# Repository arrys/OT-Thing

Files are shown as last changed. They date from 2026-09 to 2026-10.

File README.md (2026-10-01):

# OTthing

**A compact WiFi <-> OpenTherm (master & slave) interface**

## Project homepage

https://www.seegel-systeme.de/2025/01/05/ot-thing-das-universelle-wifi-opentherm-interface/

OTthing OTthing board
*OTthing board*

OTthing web UI OTthing web UI status
*OTthing web interface*

OTthing Home Assistant Dashboard OTthing Home Assistant dashboard
*Home Assistant integration*

## Overview

OTthing is a versatile OpenTherm gateway that connects your heating system to the Internet via WiFi. It acts as an OpenTherm master (controlling your boiler) and/or slave (integrating with room thermostats), providing real-time monitoring and control through a modern web interface and Home Assistant integration.

### Key Features

* **Dual OpenTherm Modes**: Operate as both an OpenTherm master and a slave simultaneously
* **Single-Board Compact Design**: Cost-efficient SMD-based single-board hardware with a small enclosure footprint
* **OpenTherm Compatibility**: Works with OpenTherm-compatible equipment that implements the functions supported by OTthing; available features vary by device
* **USB-C Powered**: Simple and reliable power supply through a standard USB-C connector
* **Web Dashboard**: Real-time status monitoring with system metrics
* **Home Assistant Integration**: Native MQTT discovery and seamless HA integration
* **Multi-Zone Support**: Control up to 2 heating circuits with independent parameters
* **Time Program**: Built-in scheduling for automatic heating setpoint changes
* **Heating Curve Control**: Outdoor-compensated flow temperature control with configurable curve parameters
* **Flow & Setpoint Management**: Fine-grained control for CH temperature targets, modes, and operating limits
* **Raw OpenTherm Tools**: Direct read/write request endpoint for diagnostics and advanced integrations
* **Real-Time Telemetry**: Live updates via WebSocket for logs and status changes
* **REST API**: Full HTTP interface for status, configuration, control commands, and topic discovery
* **WiFi Provisioning**: Built-in network scan and credential setup through the web interface
* **OTA Firmware Update**: In-browser firmware upload endpoint with automatic reboot on success
* **Local Data Export**: Device data and diagnostics export from the web UI for troubleshooting
* **External Inputs & Sensors**: Optional DS18B20, pulse input, or photointerrupter support (for example, condensate monitoring)
* **Selectable Operating Strategies**: Run OTthing as a full heating controller or in monitoring-first mode for telemetry-only operation
* **Automatic Bypass Behavior**: Allows you to restore conventional room-thermostat operation without rewiring
* **Failsafe Runtime Status**: Device health and communication state tracking for robust operation
* **Local Control**: Responsive web UI with no cloud dependency
* **Modular Design**: Extensible architecture supporting multiple integrations
* **Open-Source Platform**: Open hardware and firmware for custom extensions and modifications
* **Advanced Configuration**: Room modes (off/heat/auto), flow control, heating curves, and more
* **Detailed Logging**: Real-time log streaming to monitor system behavior
* **Turbo Mode**: Temporarily raises the flow target by a configurable amount and duration
* **Automatic Suspend**: Optional suspension based on outside temperature, room conditions, and minimum flow thresholds
* **Customizable dashboard**: add metrics to dashboard

## Architecture

The firmware consists of several functional modules:

* **OpenTherm Control** (`otcontrol.cpp`): Manages master/slave communication with the boiler
* **Master Requests** (`masterrequests.cpp`): Builds and schedules OpenTherm master requests and polling cycles
* **OpenTherm Values** (`otvalues.cpp`): Stores, normalizes, and exposes decoded OpenTherm data points
* **Heating Curve** (`heatingcurve.cpp`): Calculates the target flow temperature from heating-curve parameters
* **MQTT Integration** (`mqtt.cpp`): Publishes device state and subscribes to control topics
* **Device Status** (`devstatus.cpp`): Tracks runtime health, connectivity, and status flags
* **Auxiliary Input** (`auxInput.cpp`): Handles external input signals for additional control logic
* **Web Portal** (`portal.cpp`): Serves the responsive dashboard and API endpoints
* **Heating Control** (`CHcontrol.cpp`): Manages heating circuits, setpoints, and modes
* **Sensor Integration** (`sensors.cpp`): Collects data from external sensors
* **Configuration Management** (`devconfig.cpp`): Handles persistent device settings

## Hardware

* **MCU**: ESP32-C3 (or a compatible MCU with UART pins)
* **Communication**: OpenTherm interface
* **Power**: via USB
* **Optional**: DS18B20 1-Wire temperature sensors and auxiliary inputs

OpenTherm support and available controls depend on the boiler or other equipment. Check the device documentation and OTthing schematics before installation. Disconnect equipment from mains power before wiring; have boiler wiring performed by a qualified installer where required. Connect OpenTherm through the board's designated terminals, never directly to MCU GPIO pins.

## Installation & Setup

1. **Hardware Setup**:

   - Connect the OpenTherm slave side (boiler / ventilation / solar storage) to the **Boiler** screw terminal on OTthing
   - Optionally connect the room unit to the **Roomunit** screw terminals on OTthing
   - Connect OTthing to a USB-C power supply

2. **Access the Web Interface**:

   - The device creates a WiFi access point for provisioning or connects to its configured network
   - The default access point password is `12345678`; change it before deployment
   - Access the web UI at `http://<otthing-ip>/` (default: 4.3.2.1)

3. **Configure**:

   - Set your boiler type and heating circuit parameters
   - Configure the MQTT broker if you are using Home Assistant
   - Adjust setpoints, heating curves, and control modes

### Build and Flash (Developers)

Install PlatformIO, then run these commands from the `Firmware/` directory:

```bash
platformio run --environment release
platformio run --environment release --target upload
platformio run --environment release --target uploadfs
```

The first command builds the firmware. The next two upload the firmware and the LittleFS web assets; perform both uploads when installing a complete build. The firmware project reads access point SSID, password, and hostname from `default.ini` unless overridden by the build environment. Set a unique access point password before deploying devices.

## API Reference

OTthing exposes the following REST endpoints and WebSocket connection:

When web authentication is configured, protected endpoints require a valid login session. Requests without a valid session return 401; log in through the web UI before using these endpoints.

### Core Status Endpoints

* **`GET /`** - Web dashboard (HTML)
* **`GET /status`** - Current device and boiler status (JSON)
* **`GET /config`** - Device configuration and settings (JSON)
* **`POST /config`** - Update device configuration (JSON body)
* **`GET /otitems`** - Raw OpenTherm items and values from master and slave (JSON)
* **`GET /topics`** - List all available MQTT control topics (text/plain)

### Control Endpoints

* **`GET /set?key=value`** - Update settings via query parameters
- Examples: `/set?chSetTemp1=50`, `/set?chMode1=heat`, `/set?maxModulation=100`
  - Use `/topics` to discover supported control keys. URL-encode values when they contain reserved characters.
  - Returns 200 on success, 503 if the value cannot be set

* **`GET /slaverequest?id=X&rw=Y&data=HEX`** - Send a raw OpenTherm slave request
  - `id`: OpenTherm message ID (integer)
  - `rw`: 1 for READ_DATA, 0 for WRITE_DATA
  - `data`: Hex-encoded data value
- Returns JSON with response type, ID, and data
  - Returns 503 if a parameter is missing or the OT transaction does not complete

* **`GET /testdata`** / **`POST /testdata`** - Loopback test data for the local OT slave
  - GET returns the current table as JSON (used by `tools/settestdata.py`)
  - POST accepts a JSON object of `{"<name>": <0..65535>}` and updates the table
  - Only meaningful in loopback test mode (`otMode: 4`)

### System Endpoints

* **`GET /scan`** - Scan for available WiFi networks
  - Returns JSON with the SSID, RSSI, and channel for each network
  - Status field: -2 (scanning in progress), -1 (failed), 0+ (number of networks found)

* **`POST /setwifi`** - Configure WiFi credentials
- Parameters: `ssid` and `pass` (URL-encoded), both required
  - Starts a WiFi connection attempt; does not reboot. The device comes back
    on the new network within a few seconds

* **`GET /reboot`** - Trigger a device reboot
  - Returns 200 and schedules a reboot

* **`POST /update`** - Firmware update (binary upload)
  - Returns 200 on success, 500/503 on error
  - Triggers an automatic reboot if the update succeeds

### Real-time Communication

* **`WebSocket /ws`** - Real-time updates and log streaming
  - Receives log messages and status updates
  - Can be used to monitor device behavior in real time

### Authentication

All endpoints are open on the local network by default. Set a Web UI password in
the web interface (or via `POST /auth/setup`) to require a login. Once a password
is configured, the endpoints above require a session cookie.

* **`GET /auth/state`** - Reports whether a password is configured and whether the current session is valid
* **`POST /auth/login`** - `password` field; returns a session cookie
* **`POST /auth/logout`** - Ends the current session
* **`POST /auth/setup`** - `password` (and `delete=1`) to set or remove the password

Note that `/ws` is not covered by the session check.

## Testing & Development

A Python mock server is included for local UI and API testing. Install its dependencies and start it from the `Firmware/` directory:

```bash
python -m pip install -r requirements.txt
python tools/mock_otthing.py
```

The server listens on `http://127.0.0.1:8081/`. It is useful for UI development and API integration, but it does not replace testing against physical OpenTherm hardware.

### MQTT Notes

The device subscribes to control topics under `otthing/<device-id>/<key>/set`; `/topics` lists the supported keys. Home Assistant discovery is provided through MQTT when a broker is configured.

Changes sent through the web API are also published to the corresponding MQTT `/set` topic as retained messages. A broker can replay retained commands when the device reconnects, including after a reboot. Keep this in mind for temporary controls such as Turbo mode, and clear any stale retained command from the broker when needed.

### Troubleshooting

* **Cannot reach the web UI**: Confirm the phone or computer is connected to the OTthing access point or the same network as the device, then check the device IP.
* **No OpenTherm communication**: Check the board terminals, wiring polarity where applicable, boiler compatibility, and the device's status and logs.
* **Home Assistant entities are missing**: Confirm broker connectivity and MQTT discovery settings, then review device logs and the broker's topics.
* **A setting returns 401**: Log in through the web UI and retry the request with the browser session.
* **A temporary action returns after reboot**: Check whether a retained MQTT `/set` command is replaying it.

## Schematics

OTthing schematic 1 OTthing schematic page 1
OTthing schematic 2 OTthing schematic page 2

## Discussion

https://community.home-assistant.io/t/ot-thing-an-opentherm-wifi-gateway-with-integrated-ot-master-slave/824667

## Reporting issues

When reporting issues, please supply:

* Brand and model of the boiler and room unit
* OTthing firmware version and the steps that reproduce the issue
* Log
* Status JSON
* Configuration JSON
* OT items JSON
* Data history JSON

All of this data can be exported from OTthing using the export function at the bottom of the web UI.

## Contributing

* Make changes in a new branch based on the [`develop`](../../tree/develop) branch.
* Address only one issue per PR.
* Create the PR against the [`develop`](../../tree/develop) branch.

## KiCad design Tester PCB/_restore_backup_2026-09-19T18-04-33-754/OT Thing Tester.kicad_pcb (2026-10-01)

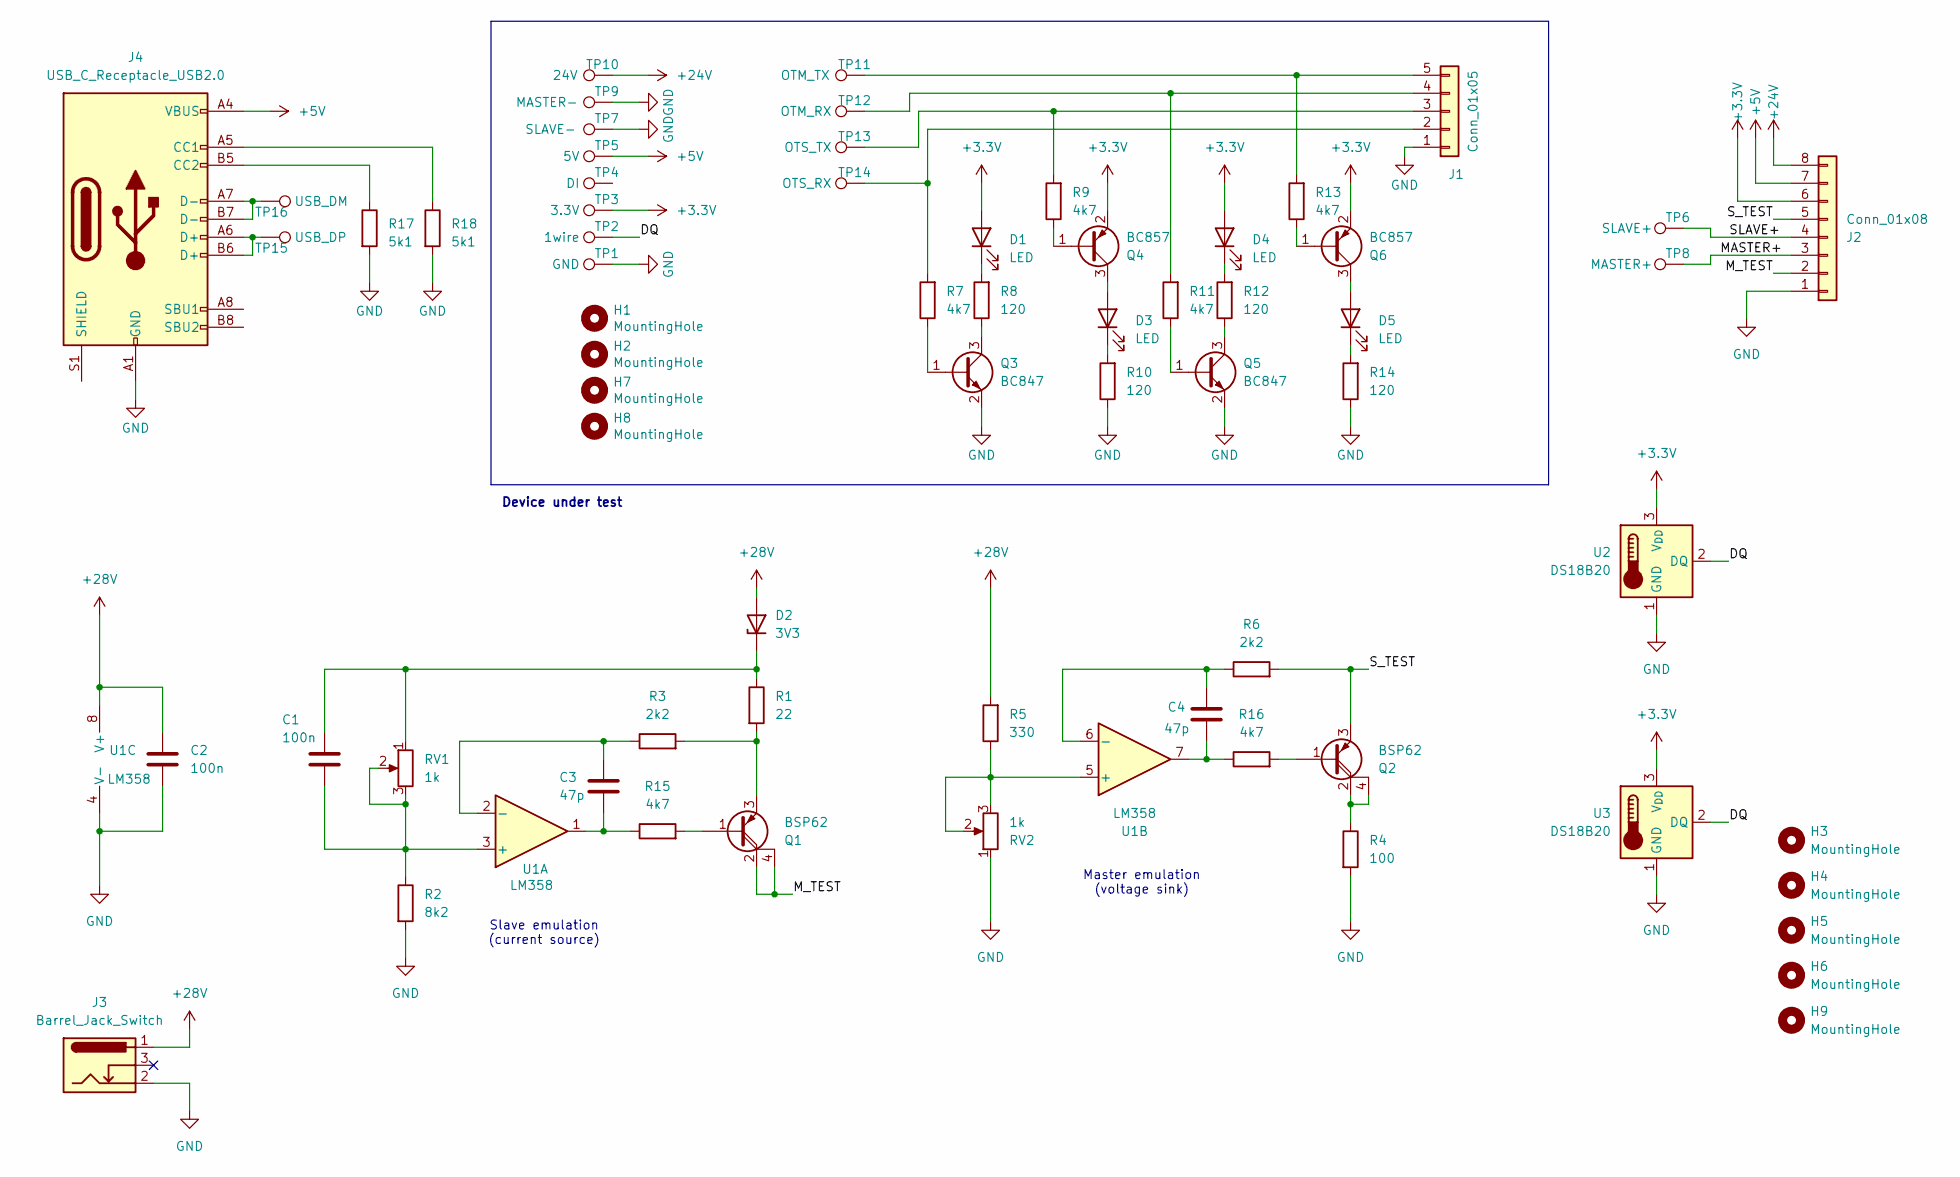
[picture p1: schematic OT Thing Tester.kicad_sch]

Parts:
C1, C2: 100n; C_0805_2012Metric
C3, C4: 47p; C_0805_2012Metric
D1, D3, D4, D5: LED; LED_0805_2012Metric
D2: 3V3; D_MiniMELF
H1, H2, H7, H8: MountingHole; MountingHole_2.7mm_M2.5
H3, H4, H5, H6, H9: MountingHole; MountingHole_3.2mm_M3_DIN965_Pad
J1: Conn_01x05; PinHeader_1x05_P2.54mm_Vertical
J2: Conn_01x08; PinHeader_1x08_P2.54mm_Vertical
J3: Barrel_Jack_Switch; BarrelJack_GCT_DCJ200-10-A_Horizontal
J4: USB_C_Receptacle_USB2.0; USB_C_Receptacle_HRO_TYPE-C-31-M-12; LCSC C2927038
Q1, Q2: BSP62; SOT-223
Q3, Q5: BC847; SOT-23
Q4, Q6: BC857; SOT-23
R1: 22; R_0805_2012Metric
R2: 8k2; R_0805_2012Metric
R3, R6: 2k2; R_0805_2012Metric
R4: 100; R_0805_2012Metric
R5: 330; R_0805_2012Metric
R7, R9, R11, R13, R15, R16: 4k7; R_0805_2012Metric
R8, R10, R12, R14: 120; R_0805_2012Metric
R17, R18: 5k1; R_0805_2012Metric; LCSC C118848
RV1, RV2: 1k; Potentiometer_Bourns_3266Y_Vertical
TP1: GND; TestPoint_THTPad_D2.0mm_Drill1.1mm
TP2: 1wire; TestPoint_THTPad_D2.0mm_Drill1.1mm
TP3: 3.3V; TestPoint_THTPad_D2.0mm_Drill1.1mm
TP4: DI; TestPoint_THTPad_D2.0mm_Drill1.1mm
TP5: 5V; TestPoint_THTPad_D2.0mm_Drill1.1mm
TP6: SLAVE+; TestPoint_THTPad_D2.0mm_Drill1.1mm
TP7: SLAVE-; TestPoint_THTPad_D2.0mm_Drill1.1mm
TP8: MASTER+; TestPoint_THTPad_D2.0mm_Drill1.1mm
TP9: MASTER-; TestPoint_THTPad_D2.0mm_Drill1.1mm
TP10: 24V; TestPoint_THTPad_D2.0mm_Drill1.1mm
TP11: OTM_TX; TestPoint_THTPad_D2.0mm_Drill1.1mm
TP12: OTM_RX; TestPoint_THTPad_D2.0mm_Drill1.1mm
TP13: OTS_TX; TestPoint_THTPad_D2.0mm_Drill1.1mm
TP14: OTS_RX; TestPoint_THTPad_D2.0mm_Drill1.1mm
TP15: USB_DP; TestPoint_THTPad_D2.0mm_Drill1.1mm
TP16: USB_DM; TestPoint_THTPad_D2.0mm_Drill1.1mm
U1: LM358; SO-8_3.9x4.9mm_P1.27mm
U2, U3: DS18B20; TO-92_Inline

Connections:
+3.3V: D1.2 (A), D4.2 (A), J2.6, Q4.2 (E), Q6.2 (E), TP3.1 (1_1), U2.3 (V_{DD}), U3.3 (V_{DD})
+5V: J2.7, J4.A4 (VBUS), J4.A9 (VBUS), J4.B4 (VBUS), J4.B9 (VBUS), TP5.1 (1_1)
+24V: J2.8, TP10.1 (1_1)
+28V: C2.1, D2.2 (A), J3.1, R5.2, U1.8 (V+)
/DQ: TP2.1 (1_1), U2.2 (DQ), U3.2 (DQ)
/MASTER+: J2.3, TP8.1 (1_1)
/M_TEST: J2.2, Q1.2 (C), Q1.4 (C)
/SLAVE+: J2.4, TP6.1 (1_1)
/S_TEST: J2.5, Q2.3 (E), R6.2
GND: C2.2, J1.1, J2.1, J3.2, J4.A1 (GND), J4.A12 (GND), J4.B1 (GND), J4.B12 (GND), Q3.2 (E), Q5.2 (E), R2.2, R4.2, R10.1, R14.1, R17.2, R18.2, RV2.1, TP1.1 (1_1), TP7.1 (1_1), TP9.1 (1_1), U1.4 (V-), U2.1 (GND), U3.1 (GND)
unnamed: C3.2, R15.1, U1.1
unnamed: C4.2, R16.1, U1.7
unnamed: D1.1 (K), R8.2
unnamed: C1.2, D2.1 (K), R1.1, RV1.1
unnamed: D3.2 (A), Q4.3 (C)
unnamed: D3.1 (K), R10.2
unnamed: D4.1 (K), R12.2
unnamed: D5.2 (A), Q6.3 (C)
unnamed: D5.1 (K), R14.2
unnamed: J1.2, R7.2, TP14.1 (1_1)
unnamed: J1.3, R9.2, TP13.1 (1_1)
unnamed: J1.4, R11.2, TP12.1 (1_1)
unnamed: J1.5, R13.2, TP11.1 (1_1)
unnamed: J4.A5 (CC1), R18.1
unnamed: J4.B5 (CC2), R17.1
unnamed: J4.A6 (D+), J4.B6 (D+), TP15.1 (1_1)
unnamed: J4.A7 (D-), J4.B7 (D-), TP16.1 (1_1)
unnamed: Q1.1 (B), R15.2
unnamed: Q1.3 (E), R1.2, R3.2
unnamed: Q2.1 (B), R16.2
unnamed: Q2.2 (C), Q2.4 (C), R4.1
unnamed: Q3.1 (B), R7.1
unnamed: Q3.3 (C), R8.1
unnamed: Q4.1 (B), R9.1
unnamed: Q5.1 (B), R11.1
unnamed: Q5.3 (C), R12.1
unnamed: Q6.1 (B), R13.1
unnamed: C1.1, R2.1, RV1.2, RV1.3, U1.3 (+)
unnamed: C3.1, R3.1, U1.2 (-)
unnamed: R5.1, RV2.2, RV2.3, U1.5 (+)
unnamed: C4.1, R6.1, U1.6 (-)

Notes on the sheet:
Master emulation (voltage sink)
Slave emulation (current source)
Device under test

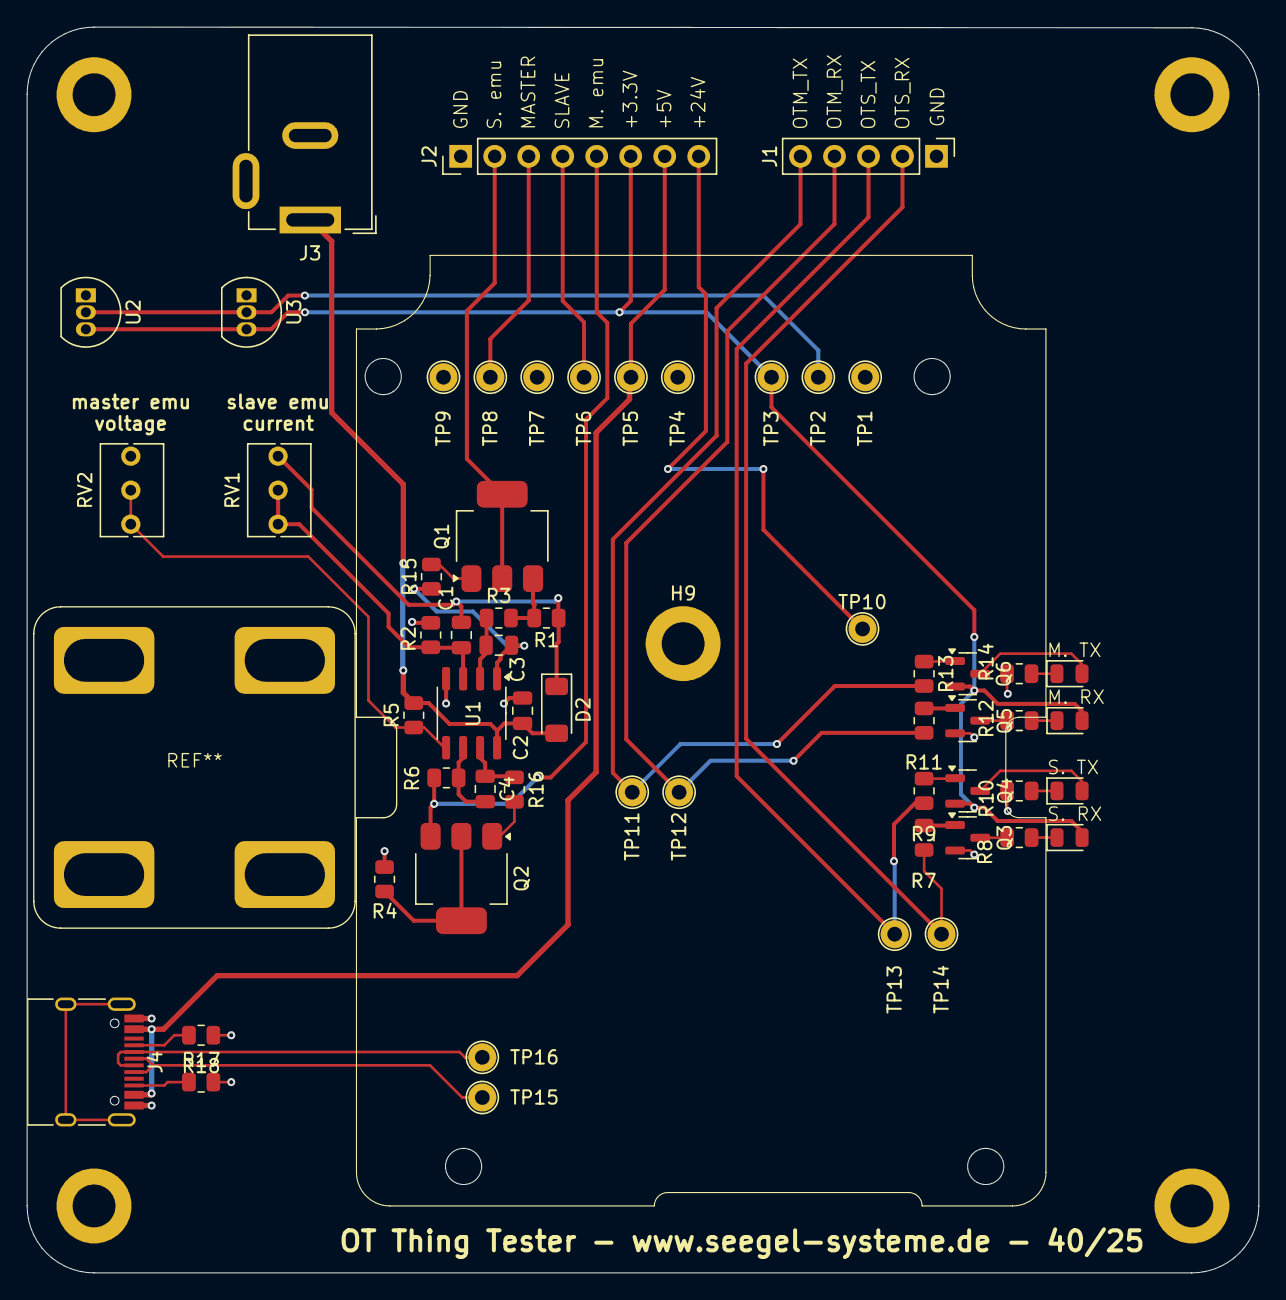
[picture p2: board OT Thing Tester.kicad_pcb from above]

Board: 2 copper layers, 92.0 x 93.0 mm, 67 parts (0 on the bottom side), 41 nets.

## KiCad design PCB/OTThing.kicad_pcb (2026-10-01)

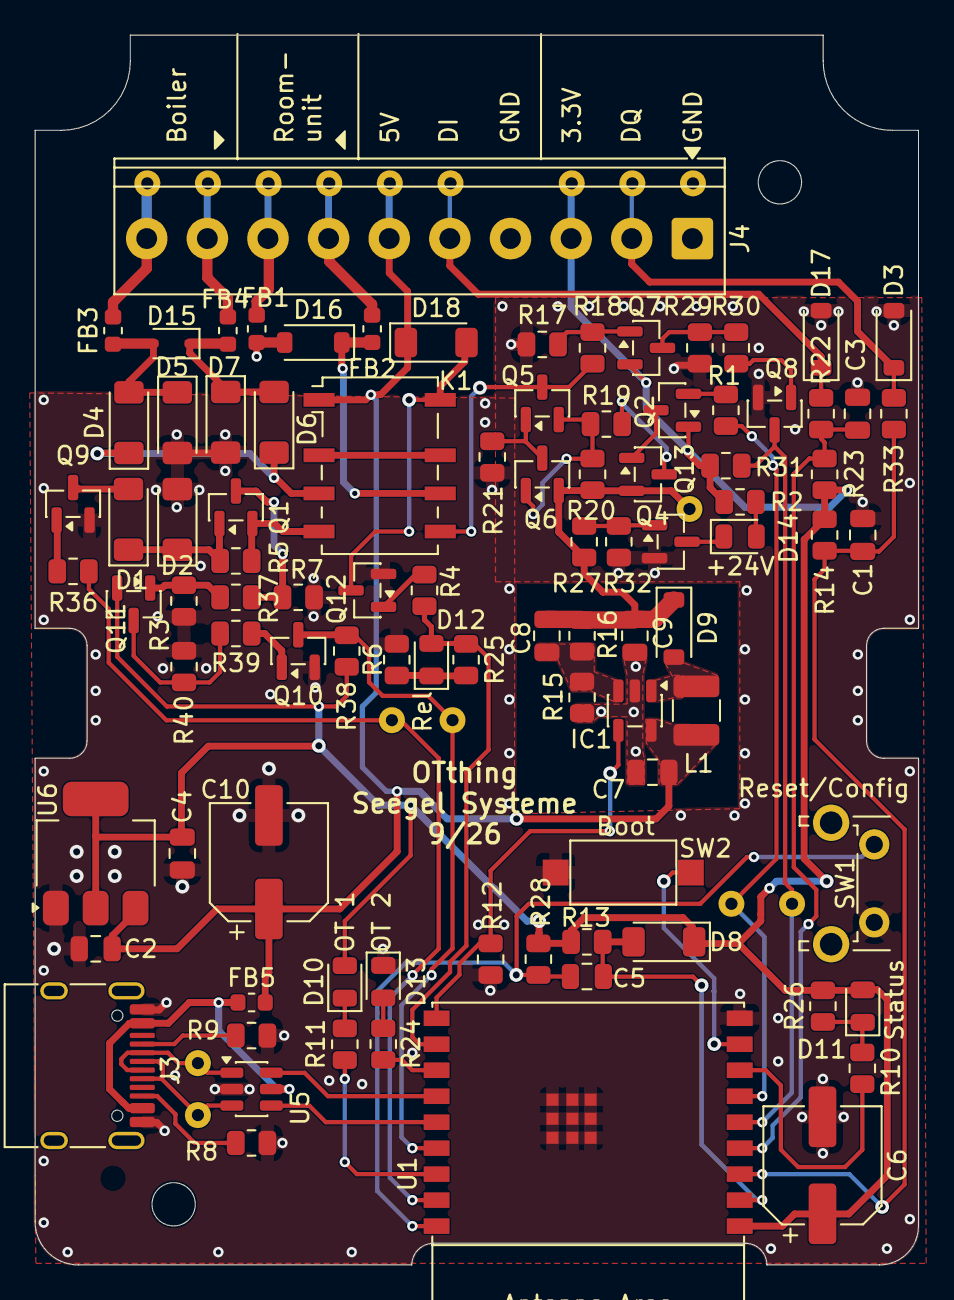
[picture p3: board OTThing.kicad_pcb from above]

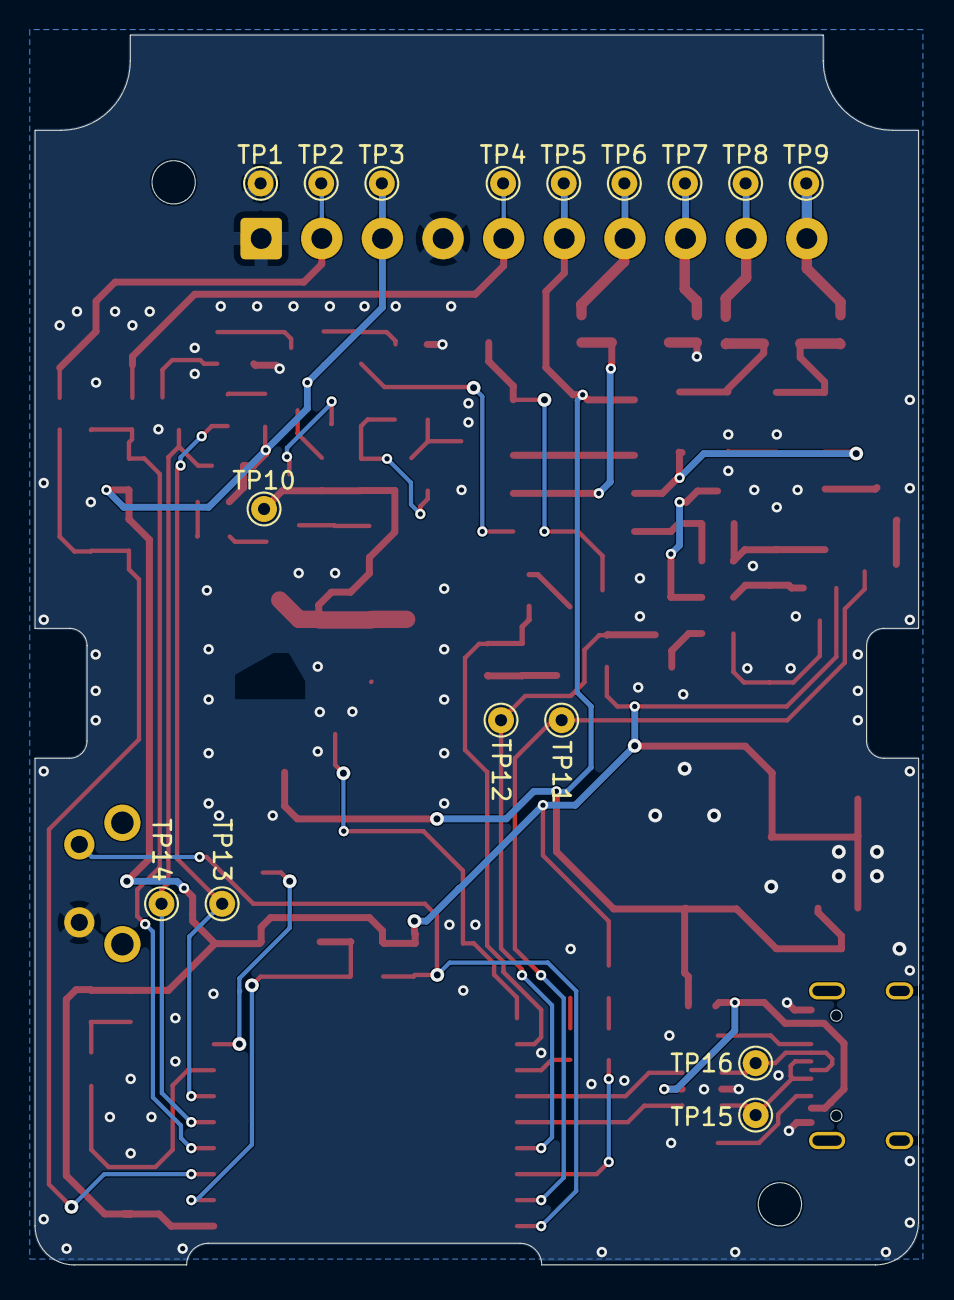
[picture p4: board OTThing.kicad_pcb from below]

Board: 2 copper layers, 51.0 x 71.0 mm, 111 parts (16 on the bottom side), 64 nets.

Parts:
C1, C3: 470pF; C_0805_2012Metric
C2, C4, C5: 10µ; C_0805_2012Metric
C6: 100µ; CP_Elec_6.3x5.4
C7, C9: 4µ7; C_0805_2012Metric
C8: 22pF; C_0805_2012Metric
C10: 470µ; CP_Elec_6.3x7.7
D1: ZMM4V3; D_MiniMELF
D2: ZMM15; D_MiniMELF
D3, D17: PTVS3V3S1UR,115; D_SOD-123
D4, D5, D6, D7, D8, D18: LL4148; D_MiniMELF
D9: MBR0540; D_SOD-123
D10: RD; LED_0805_2012Metric
D11, D13: GN; LED_0805_2012Metric
D12, D14: YL; LED_0805_2012Metric
D15: PESD24VL1BA; D_SOD-323
D16: PTVS24VS1UR; D_SOD-123
FB1, FB2, FB3, FB4, FB5: L_0603_1608Metric
H1, H2: MountingHole; MountingHole_2.5mm
IC1: TPS61041; SOT-23-5
J3: USB_C_Receptacle_USB2.0; USB_C_Receptacle_HRO_TYPE-C-31-M-12
J4: TerminalBlock_Phoenix_PT-1,5-10-3.5-H_1x10_P3.50mm_Horizont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
K1: G6K-2F-Y-5V; Relay_DPDT_Omron_G6K-2F-Y
L1: 10µ; L_1210_3225Metric
Q1, Q4, Q5, Q6, Q7, Q11: BC857C; SOT-23
Q2, Q8, Q9, Q10, Q12, Q13: BC847C; SOT-23
R1, R4, R29, R30, R31, R36, R38, R39, R40: 4k7; R_0805_2012Metric
R2, R6, R10, R11, R24: 120; R_0805_2012Metric
R3: 18k; R_0805_2012Metric
R5: 470; R_0805_2012Metric
R7, R22, R33: 330; R_0805_2012Metric
R8, R9: 5k1; R_0805_2012Metric
R12, R14, R23: 3k3; R_0805_2012Metric
R13, R21, R27: 33k; R_0805_2012Metric
R15, R25, R26, R28: 12k; R_0805_2012Metric
R16: 220k; R_0805_2012Metric
R17: 6k8; R_0805_2012Metric
R18: 22k; R_0805_2012Metric
R19: 39; R_0805_2012Metric
R20: 100; R_0805_2012Metric
R32: 1k; R_0805_2012Metric
R37: 10k; R_0805_2012Metric
SW1: RST/CONFIG; SW_Tactile_SPST_Angled_PTS645Vx83-2LFS
SW2: BOOT; SW_SPST_CK_RS282G05A3
TP1, TP2, TP3, TP4, TP5, TP6, TP7, TP8, TP9, TP10, TP11, TP12, TP13, TP14, TP15, TP16: TestPoint_THTPad_D1.5mm_Drill0.7mm
U1: ESP32-C3-WROOM-02
U5: USBLC6-2SC6; SOT-23-6
U6: AMS1117-3.3; SOT-223-3_TabPin2

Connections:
+3.3V: C4.1, C6.1, D8.1 (K), D10.2 (A), D11.2 (A), J4.3, Q2.1 (B), Q7.2 (E), Q11.2 (E), R2.2, R12.2, R13.2, R14.2, R23.2, R26.2, R31.2, R38.2, TP3.1 (1_1), U1.1 (3V3), U6.2 (VO)
+5V: C2.1, C7.1, C10.1, D18.1 (K), FB5.2, IC1.5 (VIN), J4.6, K1.1, L1.1, TP5.1 (1_1), U6.3 (VI)
+24V: C8.1, C9.1, D9.1 (K), Q4.2 (E), Q6.2 (E), R16.1, R20.2, R27.2, TP10.1 (1_1)
+VBUS: FB5.1, J3.A4 (VBUS), J3.A9 (VBUS), J3.B4 (VBUS), J3.B9 (VBUS), U5.5 (VBUS)
/CFG: C5.2, R12.1, SW1.1, U1.18 (GPIO0/ADC1_CH0/XTAL_32K_P)
/DI: D17.1 (K), J4.5, R22.1, TP4.1 (1_1)
/EN: C5.1, D8.2 (A), R13.1, U1.2 (EN/CHIP_PU)
/EN24: IC1.4 (EN), R28.1, U1.10 (GPIO10)
/OTM_RX: Q10.3 (C), R38.1, TP12.1 (1_1), U1.15 (GPIO3/ADC1_CH3)
/OTS_RX: Q8.3 (C), R31.1, TP14.1 (1_1), U1.5 (GPIO6)
/OTS_TX: R1.2, TP13.1 (1_1), U1.6 (GPIO7)
/OpenTherm interface/OTMASTER_A: FB3.2, J4.10, TP9.1 (1_1)
/OpenTherm interface/OTMASTER_B: FB4.2, J4.9, TP8.1 (1_1)
/OpenTherm interface/OTSLAVE_A: FB1.2, J4.8, TP7.1 (1_1)
/OpenTherm interface/OTSLAVE_B: FB2.2, J4.7, TP6.1 (1_1)
/REL: D12.2 (A), R4.2, R25.1, U1.11 (GPIO20/U0RXD)
/USBCDM: J3.A7 (D-), J3.B7 (D-), TP16.1 (1_1), U5.1 (I/O1)
/USBCDP: J3.A6 (D+), J3.B6 (D+), TP15.1 (1_1), U5.3 (I/O2)
GND: C1.2, C2.2, C3.2, C4.2, C6.2, C7.2, C9.2, C10.2, D2.2 (A), D3.2 (A), D5.2 (A), D7.2 (A), D13.1 (K), D16.2 (A), D17.2 (A), FB1.1, IC1.2 (GND), J3.A1 (GND), J3.A12 (GND), J3.B1 (GND), J3.B12 (GND), J4.1, J4.4, Q8.2 (E), Q9.2 (E), Q10.2 (E), Q12.2 (E), Q13.2 (E), R3.1, R6.1, R7.2, R8.2, R9.2, R15.2, R17.2, R21.1, R28.2, R29.2, R32.1, R40.2, SW1.2, SW2.2, TP1.1 (1_1), U1.9 (GND), U1.19 (GND), U5.2 (GND), U6.1 (GND)
unnamed: D1.2 (A), Q9.3 (C)
unnamed: D1.1 (K), D2.1 (K), Q1.1 (B), R5.2
unnamed: D3.1 (K), J4.2, R33.1, TP2.1 (1_1)
unnamed: D4.1 (K), D6.1 (K), K1.3
unnamed: D9.2 (A), IC1.1 (SW), L1.2
unnamed: D10.1 (K), R11.2
unnamed: D11.1 (K), R10.2, R26.1
unnamed: D12.1 (K), R6.2, R25.2
unnamed: D13.2 (A), R24.1
unnamed: D14.2 (A), R2.1
unnamed: D14.1 (K), Q13.3 (C)
unnamed: D6.2 (A), D7.1 (K), D15.1 (A1), FB4.1
unnamed: D4.2 (A), D5.1 (K), D15.2 (A2), FB3.1
unnamed: D16.1 (K), FB2.1, K1.6
unnamed: D18.2 (A), K1.8, Q12.3 (C)
unnamed: C8.2, IC1.3 (FB), R15.1, R16.2
unnamed: J3.A5 (CC1), R9.1
unnamed: J3.B5 (CC2), R8.1
unnamed: K1.2, K1.7
unnamed: Q1.3 (C), R7.1, R37.1
unnamed: K1.4, Q1.2 (E), R5.1
unnamed: Q2.3 (C), Q4.1 (B)
unnamed: Q2.2 (E), R1.1
unnamed: Q4.3 (C), R19.2
unnamed: Q5.1 (B), Q6.3 (C), R21.2
unnamed: K1.5, Q5.3 (C), R18.2
unnamed: Q5.2 (E), Q6.1 (B), R19.1, R20.1
unnamed: Q7.1 (B), R17.1, R18.1
unnamed: Q7.3 (C), R29.1, R30.2
unnamed: Q8.1 (B), R30.1
unnamed: Q9.1 (B), R36.1
unnamed: Q10.1 (B), R39.1
unnamed: Q11.1 (B), R3.2, R37.2
unnamed: Q11.3 (C), R39.2, R40.1
unnamed: Q12.1 (B), R4.1
unnamed: Q13.1 (B), R27.1, R32.2
unnamed: R11.1, U1.16 (GPIO2/ADC1_CH2)
unnamed: C1.1, R14.1, R33.2, U1.3 (GPIO4/ADC1_CH4)
unnamed: C3.1, R22.2, R23.1, U1.4 (GPIO5/ADC2_CH0)
unnamed: R10.1, U1.7 (GPIO8)
unnamed: SW2.1, U1.8 (GPIO9)
unnamed: R24.2, U1.12 (GPIO21/U0TXD)
OTM_TX: R36.2, TP11.1 (1_1), U1.17 (GPIO1/ADC1_CH1/XTAL_32K_N)
USBDM: U1.13 (GPIO18/USB_D-), U5.6 (I/O1)
USBDP: U1.14 (GPIO19/USB_D+), U5.4 (I/O2)

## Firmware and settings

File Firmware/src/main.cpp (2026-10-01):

#include <Arduino.h>
#include "hwdef.h"
#include "portal.h"
#include "otcontrol.h"
#include "mqtt.h"
#include "devstatus.h"
#include "devconfig.h"
#include "command.h"
#include "sensors.h"
#include "HADiscLocal.h"
#include "time.h"
#include "main.h"
#include "util.h"
#include "esp_task_wdt.h"
#include "auxInput.h"
#include "netw.h"
#include "StatusLed.h"

#ifdef DEBUG
    #include <ArduinoOTA.h>
#endif

bool configMode = false;

#ifdef DEBUG
// Required for DEBUG build: definitions for BLE externs referenced by command.cpp.
NimBLECharacteristic *bleSerialTx = nullptr;
volatile bool bleClientConnected = false;
#endif


void setup() {
    statusLed.begin();
    pinMode(GPIO_CONFIG_BUTTON, INPUT);
    pinMode(GPIO_BOOT_BUTTON, INPUT_PULLUP);
    pinMode(GPIO_BYPASS_RELAY, INPUT_PULLUP);

    Serial.begin();
    Serial.setTxTimeoutMs(100);

    devconfig.begin();

    otcontrol.begin();
    configMode = digitalRead(GPIO_CONFIG_BUTTON) == 0;
    
    configMode |= !netw.hasStoredWifiCredentials();

    if (configMode)
        statusLed.set(StatusLed::LED_CONFIG);

    netw.begin(configMode);
    
    AddressableSensor::begin();
    BLESensor::begin();
    haDisc.begin();
    mqtt.begin();
    configTime(devconfig.getTimezone(), 3600, PSTR("pool.ntp.org"));

    portal.begin(configMode);

    command.begin();

    esp_task_wdt_add(NULL);

#ifdef DEBUG
    ArduinoOTA.begin();
#endif
}

void loop() {
    unsigned long now = millis();

    static unsigned long btnDown = 0;
    if (digitalRead(GPIO_CONFIG_BUTTON) == 0) {
        if ((now - btnDown) > 10000) {
            statusLed.end();
            setLedStatus(true);
            devconfig.remove();
            netw.end();
            WiFi.persistent(true);
            WiFi.disconnect(true, true);
            esp_wifi_restore();
            while (digitalRead(GPIO_CONFIG_BUTTON) == 0) {
                esp_task_wdt_reset();
                yield();
            }
            ESP.restart();
        }
        esp_task_wdt_reset();
        return;
    }
    else
        btnDown = now;

    static bool oldBootButtonState = false;

    if (oldBootButtonState != (digitalRead(GPIO_BOOT_BUTTON) == 0)) {
        netw.startWps();
        oldBootButtonState = digitalRead(GPIO_BOOT_BUTTON) == 0;
    }

#ifdef DEBUG
    ArduinoOTA.handle();
#endif
    esp_task_wdt_reset();
    portal.loop();
    mqtt.loop();
    otcontrol.loop();
    Sensor::loopAll();
    devconfig.loop();
    OneWireNode::loop();

    if (configMode)
        netw.loop();

    for (int i=0; i<sizeof(auxInput) / sizeof(auxInput[0]); i++)
        auxInput[i].loop();
}

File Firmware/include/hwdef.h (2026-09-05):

#pragma once

#define GPIO_CONFIG_BUTTON 0
#define GPIO_BOOT_BUTTON 9
#define GPIO_STATUS_LED 8
#define GPIO_OTRED_LED 2
#define GPIO_OTGREEN_LED 21
#define GPIO_BYPASS_RELAY 20
#define GPIO_STEPUP_ENABLE 10
#define GPIO_1WIRE_DIO 4
#define GPIO_OTSLAVE_IN 6
#define GPIO_OTSLAVE_OUT 7
#define GPIO_OTMASTER_IN 3
#define GPIO_OTMASTER_OUT 1
#define GPIO_AUX_IN 5

inline void setLedOTRed(const bool on) {
    digitalWrite(GPIO_OTRED_LED, !on);
}

inline void setLedOTGreen(const bool on) {
    digitalWrite(GPIO_OTGREEN_LED, on);
}

inline void setLedStatus(const bool on) {
    digitalWrite(GPIO_STATUS_LED, !on);
}

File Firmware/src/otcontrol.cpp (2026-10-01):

#include <WiFi.h>
#include "otcontrol.h"
#include "auxInput.h"
#include "otvalues.h"
#include "command.h"
#include "HADiscLocal.h"
#include "mqtt.h"
#include "hwdef.h"
#include "portal.h"
#include "sensors.h"
#include "devstatus.h"

const char SLAVE_BRAND[] PROGMEM = "Seegel Systeme";

using enum OpenThermMessageID;

OTControl otcontrol;

constexpr uint16_t floatToOT(double f) {
    return (((int) f) << 8) | (int) ((f - (int) f) * 256);
}

constexpr uint16_t nib(uint8_t hb, uint8_t lb) {
    return (hb << 8) | lb;
}

// Clamp a value decoded off the OpenTherm bus to a plausible range.
// getFloat() can return up to +/-255 for any 16 bit payload, so an unclamped
// write from a room unit (or any master in repeater mode) would otherwise feed
// e.g. 255 C into the heating curve and the boiler setpoint.
static double clipOt(const double v, const double lo, const double hi) {
    if (isnan(v))
        return lo;
    return (v < lo) ? lo : ((v > hi) ? hi : v);
}

static double otFloat(const uint32_t msg, const double lo, const double hi) {
    return clipOt(OpenTherm::getFloat(msg), lo, hi);
}

// Testdata for local OT slave, can be read by a connected master
struct OTTestItem loopbackTestData[51] = {
    {Status,                    0x0000}, // no flags set
    {SConfigSMemberIDcode,      nib(1<<0 | 1<<2 | 1<<5, 1)}, // DHW, cooling, CH2 present, Member ID 1
    {SConfigSMemberIDCodeVentilationHeatRecovery, nib(1<<0 | 1<<1 | 1<<2, 1)}, // heat recovery, bypass present, variable speed control present, Member ID 1
    {ASFflags,                  0x0000}, // no error flags, oem error code 0
    {RBPflags,                  0x0101},
    {TrOverride,                0},
    {MaxCapacityMinModLevel,    nib(20, 5)}, // 20 kW / 5 %
    {RelModLevel,               floatToOT(33.3)},
    {CHPressure,                floatToOT(1.25)},
    {DHWFlowRate,               floatToOT(2.4)},
    {Tboiler,                   floatToOT(48.5)},
    {Tdhw,                      floatToOT(37.5)},
    {Toutside,                  floatToOT(3.5)},
    {Tret,                      floatToOT(41.7)},
    {TflowCH2,                  floatToOT(48.6)},
    {Tdhw2,                     floatToOT(37.6)},
    {Texhaust,                  90},
    {TrOverride2,               0},
    {TdhwSetUBTdhwSetLB,        nib(60, 40)}, // 60 °C upper bound, 40 °C lower bound
    {MaxTSetUBMaxTSetLB,        nib(60, 25)}, // 60 °C upper bound, 20 °C lower bound
    {PowerCycles,               159},
    {SuccessfulBurnerStarts,    9999},
    {CHPumpStarts,              7777},
    {DHWPumpValveStarts,        5544},
    {DHWBurnerStarts,           9955},
    {BurnerOperationHours,      8888},
    {CHPumpOperationHours,      6666},
    {DHWPumpValveOperationHours,5555},
    {DHWBurnerOperationHours,   2222},
    {OpenThermVersionSlave,     nib(2, 2)},
    {SlaveVersion,              nib(4, 4)},
    {StatusVentilationHeatRecovery, 0x001E},
    {RelVentLevel,              55}, // relative ventilation 0..100 %
    {RHexhaust,                 45},
    {CO2exhaust,                1450}, // PPM
    {Tsi,                       floatToOT(22.1)},
    {Tso,                       floatToOT(22.2)},
    {Tei,                       floatToOT(22.3)},
    {Teo,                       floatToOT(22.1)},
    {RPMexhaust,                2300},
    {RPMsupply,                 2400},
    {ASFflagsOEMfaultCodeVentilationHeatRecovery,   0x0F33},
    {OpenThermVersionVentilationHeatRecovery,       0x0105},
    {VentilationHeatRecoveryVersion,                0x0107},
    {RemoteOverrideFunction,    0x0000},
    {UnsuccessfulBurnerStarts,  19},
    {FlameSignalTooLowNumber,   4},
    {OEMDiagnosticCode,         123},
    {TboilerHeatExchanger,      floatToOT(48.5)},
    {BoilerFanSpeedSetpointAndActual, nib(20, 21)},
    {FlameCurrent,              floatToOT(96.8)},
};

class SemMaster {
private:
    BaseType_t result;
public:
    SemMaster(const uint16_t timeout) {
        result = xSemaphoreTakeRecursive(otcontrol.master.mutex, (TickType_t) timeout / portTICK_PERIOD_MS);
        wait();
    }

    ~SemMaster() {
        if (result == true) {
            wait();
            xSemaphoreGiveRecursive(otcontrol.master.mutex);
        }
    }

    operator bool() {
        return (result == pdTRUE) && otcontrol.master.hal.isReady();
    }

    void wait() {
        if (result == pdTRUE) {
            TickType_t start = xTaskGetTickCount();

            while (!otcontrol.master.hal.isReady()) {
                if ((xTaskGetTickCount() - start) > pdMS_TO_TICKS(2000))
                    break;

                otcontrol.hwYield();
            }
        }
    }
};

void IRAM_ATTR handleIrqMaster() {
    otcontrol.masterPinIrq();
}

void IRAM_ATTR handleIrqSlave() {
    otcontrol.slavePinIrq();
}

//OpenTherm master callback
void otCbMaster(unsigned long response, OpenThermResponseStatus status) {
    otcontrol.OnRxMaster(response, status);
}

//OpenTherm slave callback
void otCbSlave(unsigned long response, OpenThermResponseStatus status) {
    otcontrol.OnRxSlave(response, status);
}

OTControl::OTInterface::OTInterface(const uint8_t inPin, const uint8_t outPin, const bool isSlave):
        hal(inPin, outPin, isSlave) {
    resetCounters();
    mutex = xSemaphoreCreateRecursiveMutex();
}

bool OTControl::OTInterface::sendRequest(const char source, const unsigned long msg) {
    const bool sent = hal.sendRequestAsync(msg);

    if (sent) {
        if (source)
            command.sendOtEvent(source, msg);
        txCount++;
        lastTx = millis();
        lastTxMsg = msg;
    }

    return sent;
}

void OTControl::OTInterface::resetCounters() {
    txCount = 0;
    rxCount = 0;
    timeoutCount = 0;
    invalidCount = 0;
}

void OTControl::OTInterface::onReceive(const char source, const unsigned long msg) {
    if (source)
        command.sendOtEvent(source, msg);
    rxCount++;
    lastRx = millis();
}

void OTControl::OTInterface::sendResponse(const char source, const unsigned long msg) {
    uint32_t temp = millis();

    while (true) {
        if (hal.sendResponse(msg)) {
            if (source)
                command.sendOtEvent(source, msg);
        
            txCount++;
            lastTx = millis();
            lastTxMsg = msg;
            break;
        }
        if (millis() - temp > 300)
            break;

        hal.process();
        yield();
    }
}

OTControl::OTControl():
        lastBoilerStatus(0),
        otMode(OTMODE_LOOPBACKTEST),
        slaveApp(SLAVEAPP_HEATCOOL),
        chcontrol{CHcontrol(0), CHcontrol(1)},
        setBoilerRequest{OTWRSetBoilerTemp(0), OTWRSetBoilerTemp(1)},
        setRoomTemp{OTWRSetRoomTemp(0), OTWRSetRoomTemp(1)},
        setRoomSetPoint{OTWRSetRoomSetPoint(0), OTWRSetRoomSetPoint(1)},
        master(GPIO_OTMASTER_IN, GPIO_OTMASTER_OUT, false),
        slave(GPIO_OTSLAVE_IN, GPIO_OTSLAVE_OUT, true) {
}
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

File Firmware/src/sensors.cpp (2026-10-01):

#include "sensors.h"
#include <DallasTemperature.h>
#include "HADiscLocal.h"
#include "devstatus.h"

Sensor roomTemp[2] = {
    Sensor(0.2),
    Sensor(0.2)
};
AutoSensor roomSetPoint[2];
OutsideTemp outsideTemp;
Sensor returnTemp[2] = {
    Sensor(0.4),
    Sensor(0.4)
};

SemaphoreHandle_t AddressableSensor::mutex;
Sensor* Sensor::lastSensor = nullptr;
uint32_t Sensor::lastSmooth = 0;
BLESensor* BLESensor::last = nullptr;
OneWireNode *OneWireNode::last = nullptr;
static OneWire oneWire;

class SensorLock: public SemHelper {
public:
    SensorLock(): SemHelper(AddressableSensor::mutex, 100) {    
    }
};

Sensor::Sensor(const double alpha):
    src(SOURCE_NA),
    setFlag(false),
    alpha(alpha) {
    prevSensor = lastSensor;
    lastSensor = this;
}

void Sensor::set(const double val, const Source src, const Source lastSrc) {
    if ((src == this->src) || (src == SOURCE_NA)) {
        value = val;
        if ((!setFlag) || (alpha == 1.0))
            smoothed = val;
        setFlag = true;
        lastSetSrc = src;
        if (lastSrc != SOURCE_NA)
            lastSetSrc = lastSrc;
        else if (lastSrc != SOURCE_NA)
            lastSetSrc = lastSrc;
    }
}

void Sensor::updateSmooth() {
    smoothed = alpha * value + (1.0 - alpha) * smoothed;
}

bool Sensor::get(double &val, const bool raw) {
    if (src == SOURCE_BLE) {
        SensorLock lock;
        if (!lock)
            return false;

        auto *sensor = BLESensor::find(adr);
        if (sensor != nullptr)
            set(sensor->temp, SOURCE_BLE);
    }

    if (setFlag) {
        if (raw)
            val = value;
        else
            val = smoothed;
        val = round(val * 10) / 10;
    }
    
    return setFlag;
}

void Sensor::writeJson(JsonVariant val) {
    double d;
    if (!get(d))
        val.set(nullptr);
    else {
        JsonObject obj = val.to<JsonObject>();
        obj[F("current")] = round(smoothed * 10) / 10;
        obj[F("raw")] = round(value * 10) / 10;
        obj[STR_STATKEY_LASTSETPOINTSRC] = lastSetSrc;
    }
}

Sensor::operator bool() const {
    return setFlag;
}

std::vector<Sensor*> Sensor::findByOwn(const OneWireNode *own) {
    std::vector<Sensor*> result;
    Sensor *item = lastSensor;
    while (item) {
        if (item->own == own)
            result.push_back(item);
        item = item->prevSensor;
    }
    return result;
}

void Sensor::setConfig(JsonObject &obj) {
    auto newSrc = (Source) (obj["source"] | (int) SOURCE_NA);
    if (src != newSrc) {
        setFlag = false;
        src = newSrc;
    }
    
    own = nullptr;
    switch (src) {
    case SOURCE_1WIRE:
        own = OneWireNode::find(String(obj["adr"]));
        setFlag = false;
        break;

    case SOURCE_BLE:
        for (int i=0; i<6; i++)
            adr[i] = strtol(String(obj[F("adr")]).substring(i * 2, i * 2 + 2).c_str(), 0, 16);
        break;

    default:
        break;
    }
}

bool Sensor::isMqttSource() {
    return (src == SOURCE_MQTT) || (src == SOURCE_AUTO);
}

bool Sensor::isOtSource() {
    return (src == SOURCE_OT);
}

void Sensor::loopAll() {
    const bool smooth = ((millis() - lastSmooth) >= 60000);
    if (smooth)
        lastSmooth = millis();
    
    Sensor *item = lastSensor;
    while (item) {
        item->loop();
        if (smooth && item->setFlag)
            item->updateSmooth();
        item = item->prevSensor;
    }
}

AutoSensor::AutoSensor():
    Sensor(1.0) {
    memset(values, 0, sizeof(values));
}

void AutoSensor::set(const double val, const Source src, const Source lastSrc) {
    if ((this->src == SOURCE_AUTO) && (src != SOURCE_NA)) {
        if (val != values[src]) {
            Sensor::set(val, SOURCE_AUTO, lastSrc);
            values[src] = val;
        }
    }
    else
        Sensor::set(val, src, lastSrc);
}

OutsideTemp::OutsideTemp():
        Sensor(0.2),
        nextMillis(0),
        httpState(HTTP_IDLE) {

    acli.onData([this](void *arg, AsyncClient *client, void *data, size_t len) {
        replyBuf += String((char*) data, len);
    });

    acli.onDisconnect([](void *arg, AsyncClient *client) {
        client->close();
    });

    acli.onError([](void *arg, AsyncClient *client, int8_t error) {
        client->close();
    });
}

void OutsideTemp::setConfig(JsonObject &obj) {
    Sensor::setConfig(obj);
    lat = obj[F("lat")];
    lon = obj[F("lon")];
    apikey = obj[F("apikey")].as<String>();
    interval = (uint16_t) obj[F("interval")] * 1000;
    if (interval == 0)
        interval = 30000;
    owResult.clear();
    nextMillis = 0;
}

void OutsideTemp::set(const double val, const Source src, const Source lastSrc) {
    Sensor::set(val, src, lastSrc);

    struct tm timeinfo;
    if (!getLocalTime(&timeinfo, 0))
        return;

    const int currentHour = timeinfo.tm_hour;
    if (lastHistPos < 0) {
        // first call ever: seed all hourly slots so avg is not skewed by zeros
        for (int i=0; i<sizeof(minValues)/sizeof(minValues[0]); i++)
            minValues[i] = maxValues[i] = val;
    }
    else if (currentHour != lastHistPos)
        minValues[currentHour] = maxValues[currentHour] = val;

    lastHistPos = currentHour;
    if (val < minValues[currentHour])
        minValues[currentHour] = val;
    if (val > maxValues[currentHour])
        maxValues[currentHour] = val;
}

void OutsideTemp::writeJson(JsonVariant val) {
    Sensor::writeJson(val);
    if (!setFlag)
        return;

    JsonObject obj = val.as<JsonObject>();
    double minVal = value, maxVal = value;
    for (int i=0; i<sizeof(minValues)/sizeof(minValues[0]); i++) {
        if (minValues[i] < minVal)
            minVal = minValues[i];
        if (maxValues[i] > maxVal)
            maxVal = maxValues[i];
    }
    obj[F("min")] = minVal;
    obj[F("max")] = maxVal;
    obj[F("avg")] = getAvg();
}

double OutsideTemp::getAvg() const {
    double avgVal = 0;
    for (int i=0; i<sizeof(minValues)/sizeof(minValues[0]); i++) {
        avgVal += (minValues[i] + maxValues[i]) / 2.0;
    }
    return avgVal / (sizeof(minValues)/sizeof(minValues[0]));
}
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

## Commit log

2026-09-05 Use ASCII labels for temperature and current units
2026-10-01 Fix OpenTherm value decoding and request accounting
    Values decoded off the OT bus were used without any upper bound. getFloat()
    returns up to +/-255 for any 16 bit payload, so a single malformed write from
    a room unit (or any master in repeater mode) could feed e.g. 255 C into the
    heating curve and the boiler setpoint. Added clipOt()/otFloat() and applied
    per-message plausible ranges: flow 0-100, room setpoint 5-35, DHW 5-80,
    outside -50-60, room temp 0-50.
    DayTime day-of-week was computed as (((tm_wday + 1) % 7) + 1), which mapped
    every single day wrong (Sun->2, Sat->1). The OT field is 1=Monday..7=Sunday
    while tm_wday is 0=Sunday, so Sunday is the only wrap.
    Slave Status replies were bui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
    [otcontrol.cpp]
2026-10-01 Fix use-after-free in the OT event TCP command server
    onClientDisconnect() was empty, but sendAll() iterates the client vector and
    calls write() on every OpenTherm transaction. AsyncTCP destroys the AsyncClient
    once the disconnect callback returns, so the retained pointer was dangling:
    any client that connected and disconnected left a freed object that the next
    OT event wrote through. The vector also grew without bound for the life of the
    device, since nothing ever removed an entry.
    The vector is mutated from the AsyncTCP task and iterated from the loop task,
    so push_back could reallocate during iteration. Guard it with the project's
    existing SemHelper, cap concurrent clients, and check con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
2026-10-01 Use non-deprecated AsyncClient::close() in sensors
    close(bool) is deprecated in AsyncTCP; close() is the current signature.
    Clears the last three warnings in project code under -Wall -Wextra.
2026-10-01 Make release builds reproducible and fail loudly without minify-html
    gzip.compress() embeds the current mtime by default, so the generated
    include/html.h changed bytes on every invocation. That forced a recompile of
    portal.cpp on every run and made two builds of the same source produce
    different firmware.bin, which matters because CI publishes that binary to
    GitHub Releases. Pass mtime=0; two consecutive builds are now byte-identical.
    A release build silently skipped HTML minification when minify-html was
    missing. helper.py runs inside PlatformIO's own penv interpreter rather than
    the project venv, so `pip install -r requirements.txt` does not provide it
    there and the release image shipped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
2026-10-01 Fix web UI crashes, NaN curves and dead recent-events list
    The device stores posted config verbatim with no schema validation, and the UI
    replaced its defaults wholesale with it, so several code paths dereferenced
    nested keys that could legitimately be absent. A config with only one heating
    circuit, or without returnLimit, threw inside consumeStatusCache() and
    silently stopped most of the dashboard.
    - guarded config.heating[currentCh], hcfg.returnLimit and the curve axes, and
    added ensureHeatingConfig() to materialise a missing circuit from the
    defaults before use
    - statuscache.mqtt?.basetopic and the runtime formatting are now guarded; a
    payload without mqtt aborted the render before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
2026-10-01 Verify flash writes and fix production flashing correctness
    write_flash() returns per-segment MD5 verify results, which were discarded
    while "uploaded successfully" printed unconditionally. Any partial or failed
    write was reported as success and batch_upload continued to ALL STEPS PASSED,
    which is the worst possible failure mode for a tool that bricks devices.
    Check every segment, and fail if the result carries no verify report.
    verify_tcp_stream() required a strict T->S->P->B cycle, but a freshly flashed
    device in master mode only ever emits T/B/A/E: S/P/R appear only while a room
    unit polls the slave port. The check could therefore never pass, so
    verify_http_page, configure_device and dev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
    [production.py]
2026-10-01 Make the mock server match the firmware API contract
    Several endpoints diverged from the firmware, which made UI work against the
    mock misleading:
    - /topics and /testdata were not implemented at all, so the MQTT basetopic
    link 404'd and settestdata.py could not target the mock
    - /otitems returned an invented {"items": [...]} shape; the firmware returns
    three sibling objects (slave/master/roomunit) mapping each OT value name to
    {id, enabled, lastMsgType, numSet, value, disc}
    - /slaverequest used made-up field names and omitted "type", and never
    returned 503 for missing parameters
    - /set accepted only 13 of the 30 firmware topics and silently answered 200 for
    everything else; ventEn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
    [mock_otthing.py]
2026-10-01 Decode OT message 100 from the low byte and fix reconnect busy-looping
    FLAG_BITS[100] declared the flags under "hb", but message 100 is an 8 bit
    value and the firmware tests bits 0/1 of the low byte (OTValueFlags in
    otvalues.h). The card always rendered both flags as clear regardless of the
    wire value. Move them to "lb" and add the matching flag8/lb decode branch.
    The websocket reader had no backoff on the read-timeout path, so a reachable
    but silent device produced a full reconnect every rxTimeout (2 s by default).
    Each one appended a "# connected" note, and with MAX_HISTORY at 500 that
    flushed roughly 17 minutes of real traffic out of the ring buffer. Add
    exponential backoff on every exit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
    [loganalyzer.py, settestdata.py]
2026-10-01 Correct the API reference in the README
    - /set?flowSetTemp=45 was not a real topic; mqtt.setValue() returns UNKNOWN for
    it and the endpoint answers 503, so the documented example failed
    - POST /setwifi does not reboot the device; it starts a connection attempt and
    returns. It also requires both ssid and pass.
    - /slaverequest returns 503 when a parameter is missing or the transaction does
    not complete, which was undocumented
    - /testdata (GET and POST) was missing entirely
    - document the /auth/* endpoints, and note that auth is off until a password is
    configured and that /ws is not covered by the session check
2026-10-01 Ignore generated bytecode and operator-local files
    __pycache__/ and *.pyc are produced by running the tools in Firmware/tools.
    devicelist.txt is appended with real device MAC addresses by production.py.
    secrets.ini may hold real credentials.
2026-10-05 Fix intermittent loss of heat pump cooling capability
    OnRxMaster latched frames that failed the OpenTherm parity/format check into
    the OTValue caches. Slave config is polled only once (interval 0) and
    sendDiscovery() runs inside that single setValue(), so one corrupt frame on the
    first request after boot pinned DHW/cooling/CH2 capability at "absent" until a
    reboot or OT mode change. OnRxSlave already guarded this; the master path did
    not. Invalid frames now behave like timeouts: counted, then retried.
    Also gate all emitted cooling state on the capability bit. SLAVEAPP_HEATCOOL is
    the default and every heat pump has the heating channel, so it cannot stand in
    for cooling -- not all heat pumps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
2026-10-05 Add native tooltips across the UI
    Every field-driven element, button and input now has a title= tooltip.
    Coverage goes from 37 titles to 347, with no gaps left:
    field= elements 244/244
    <button> 54/54 title + aria-label
    <input> 71/71
    Descriptions are written per field path from the firmware's actual semantics
    rather than generated from the path, so they explain the value. For example
    slave.slave_config_member.cooling_config reads "Appliance supports reversing to
    cool (slave config bit 2). Not all heat pumps can cool", and the heating
    hysteresis params say which threshold they damp.
    Mechanism is the native title attribute, matching what the file already did for
    b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
2026-10-05 Fix misleading-indentation warning in getFlowTempSimple
    The line after the new guard was tab-indented while the rest of the function
    body uses four spaces, so gcc read it as a continuation of the if body:
    src/heatingcurve.cpp:77:5: warning: this 'if' clause does not guard
    all statements in its body [-Wmisleading-indentation]
    Release builds enable -Wall -Wextra, and this was the only warning left in
    Firmware/src; everything else comes from the OpenTherm submodule, the async
    libraries or the Arduino WiFi framework. Also drops a stray trailing space.
    Whitespace only, no semantic change. Verified by rebuilding twice: with
    identical source the release image is byte-i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
2026-10-05 Make dev branch builds explicit on GitLab CI
    Two problems with the previous pipeline:
    1. build:branch gated on $CI_DEFAULT_BRANCH for the default branch. That is a
    project setting which on this instance is not guaranteed to be main, so dev
    builds were only covered by the second rule as an accident of ordering. dev,
    main, master and release are now each listed explicitly, so a dev build does
    not depend on project configuration.
    2. The minify-html step assumed PlatformIO keeps a penv and probed
    $PLATFORMIO_CORE_DIR/penv/bin/python. PlatformIO 6 does not create a penv
    when pip-installed: it runs helper.py in whichever interpreter hosts
    platformio. In the python:3.12-slim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
2026-10-05 Fix room-compensation mode switching off heating; add cooling override
    Two defects found against a live Brötje MONO AWHP 11 TR.
    1. getChOn() treated the room-compensation mode as a demand signal:
    if ((mode == MODE_OFF) || (roomComp.mode == MODE_OFF) || (getFlow() == 0.0))
    return false;
    roomComp.mode is the compensation mode, not a request. getFlow() already
    omits the compensation offset when it is off, so the extra clause only ever
    switched the whole circuit off. Observed live: roomMode "off" with
    ch_enable false and ch_set_t pinned to the 10 C off temperature, so the
    appliance only ever ran DHW and relative modulation read only 0 or 100.
    Setting roomM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
2026-10-05 Add a button and API to re-poll appliance capabilities
    Both slave-config values are read with interval 0, i.e. once, the first time a
    reply arrives. That is fine for a genuinely fixed capability but wrong for an
    appliance whose reported capability depends on its current mode or the season:
    a heat pump that only advertises cooling while it is in cooling mode would be
    latched as "no cooling" until the device is power-cycled.
    - OTControl::repollCapabilities() unsets both slave-config values so process()
    asks again, and clears discFlag so discovery re-runs and Home Assistant
    entities follow the new answer.
    - GET /repollcaps triggers it and returns the cached word plus
    {"scheduled": true}.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
